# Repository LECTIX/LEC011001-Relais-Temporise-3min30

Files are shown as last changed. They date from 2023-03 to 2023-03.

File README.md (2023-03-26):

# LEC011001-Relais-Temporise-3min30
Fichiers sources pour le produit LEC011001

## Description du produit

Lorsque les 2 bornes BTN sont reliées via un bouton poussoir, un ILS ou équivalent, le relais reste activé pour une temporisation réglable entre 1s et 3min 30s.

- **ACTIVATION** Reliez les 2 bornes (avec un bouton poussoir, ILS, ou équivalent) pour enclencher le relais pour un temps réglable de 1s à 3min 30s.
- **RÉGLAGE** Réglez simplement la temporisation en utilisant un tournevis pour ajuster le potentiomètre.
- **ALIMENTATION** 8 – 16 V DC / AC (12V DC recommandé)
- **APPLICATIONS** Déclenchez facilement automatismes, animations et éclairages pendant un certain temps, ou après un certain délais.

## Utiliser les fichiers sources pour fabriquer le produit

Il n'est **pas nécessaire de savoir souder ou d'être bon en électronique** pour se procurer ce produit. Grâce aux fichiers sources publiés ici, vous pouvez être en mesure de faire fabriquer ce produit par un sous traitant.

### Faire fabriquer chez un sous traitant

Il est aujourd'hui possible de faire fabriquer à moindre cout des cartes électroniques. Nous recommendons [JLCPCB](https://jlcpcb.com/) si vous voulez aller au moins cher. Si vous préférez un acteur européen, [eurocircuits](https://www.eurocircuits.com/) est un des acteurs reconnus.

tuto (http://www.youtube.com/watch?v=RXGGvsUtz0c "TUTO : faire fabriquer un produit LECTIX")

1. Télécherger les sources de ce produit en cliquant sur le bouton `Code`, puis `Download ZIP`.
1. Décompresser le dossier.
1. Les fichiers pour la fabrication se trouvent dans le répertoire `hardware/prod`.
1. Se connecter sur [https://cart.jlcpcb.com/quote](https://cart.jlcpcb.com/quote)
1. Cliquer sur le bouton `Add gerber file` et sélectionner le fichier `gerbers.zip`.
1. Sélectionnez la quantité de cartes que vous souhaitez dans le champs `PCB Qty`.
1. Laisser toutes les autres options par défaut, puis cliquez sur le toggle switch en face de `PCB Assembly`, et enfin sur le bouton `confirm`.
1. Une preview de la carte électronique sans les composants doit apparaitre. Cliquez sur `NEXT`.
1. Cliquez sur le bouton `Add BOM File`, puis sélectionnez le fichier `bom.csv`
1. Cliquez sur le bouton `Add CPL File`, puis sélectionnez le fichier `pos.csv`
1. **Vérifier que tous les composants sont en stock** et bien sélectionnés, puis cliquez sur `NEXT`.
1. Une preview de la carte avec ses composants apparait. Continuer le chemin en cliquant sur `NEXT`.
1. Le prix final apparait. Sélectionnez la catégorie du produit, puis cliquez sur `SAVE TO CART`.
1. Une fois sauvegardé dans votre panier, vous pouvez valider votre commande et choisir le moyen d'acheminement. Afin de ne pas avoir à se préoccuper des frais de douane, nous vous conseillons de choisir une méthode d'expédition DDP.

Vous receverez vos cartes sous 1 à 3 semaines. 

**Nous ne sommes en aucun cas responsables des cartes qui arriveraient défectueuses ou non fonctionnelles.**

### Modifications des fichiers sources

Installez kicad 6 (ou version supérieure), et ouvrez le fichier LEC011001.kicad_pro

### Regénérer les fichiers gerber, BOM, et position (Optionnel)

Peut se faire simplement en utilisant kikit :

```
cd hardware
docker run --rm -w /kikit -v $PWD:/kikit yaqwsx/kikit kikit fab jlcpcb --assembly --no-drc --schematic LEC011001.kicad_sch --field LCSC --corrections JLCPCB_CORRECTION --nametemplate LEC011001_{} LEC011001.kicad_pcb prod/

```
## Notices

[Manuel FR](docs/manual_fr.pdf)

## License
Tous nos fichiers sont plubliés sous la license CERN Open Hardware Licence Version 2 - Strongly Reciprocal

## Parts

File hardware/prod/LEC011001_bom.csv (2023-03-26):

Comment | Designator | Footprint | LCSC
100uF | C1,C3,C7 | 0_capacitors:CP_Elec_6.3x5.8 | C249982
100nF | C2,C4,C5,C6,C8 | Capacitor_SMD:C_0603_1608Metric | C14663
MB10S | D1 | Package_TO_SOT_SMD:TO-269AA | C2488
LED | D2 | LED_SMD:LED_0603_1608Metric | C72043
D | D3 | Diode_SMD:D_SMA | C95872
Button | J1 | 0_connectors:TerminalBlock_bornier-2_P5.08mm-blue | C395882
PWR | J2 | 0_connectors:TerminalBlock_bornier-2_P5.08mm-green | C395849
CONTACT_1 | J3 | 0_connectors:TerminalBlock_bornier-3_P5.08mm-blue | C395881
CONTACT_2 | J4 | 0_connectors:TerminalBlock_bornier-3_P5.08mm-blue | C395881
HK19F-5V | K1 | 0_relays:Relay_DPDT_HK19F | C54512
S8050 | Q1 | Package_TO_SOT_SMD:SOT-23 | C2146
10k | R1,R2,R4 | Resistor_SMD:R_0603_1608Metric | C25804
1k | R3 | Resistor_SMD:R_0603_1608Metric | C21190
2M | RV1 | 0_potentiometers:Potentiometer_3296W_Vertical | C118923
MC78M05_TO252 | U1 | Package_TO_SOT_SMD:TO-252-2 | C58069
NE555D | U2 | Package_SO:SOIC-8_3.9x4.9mm_P1.27mm | C7593

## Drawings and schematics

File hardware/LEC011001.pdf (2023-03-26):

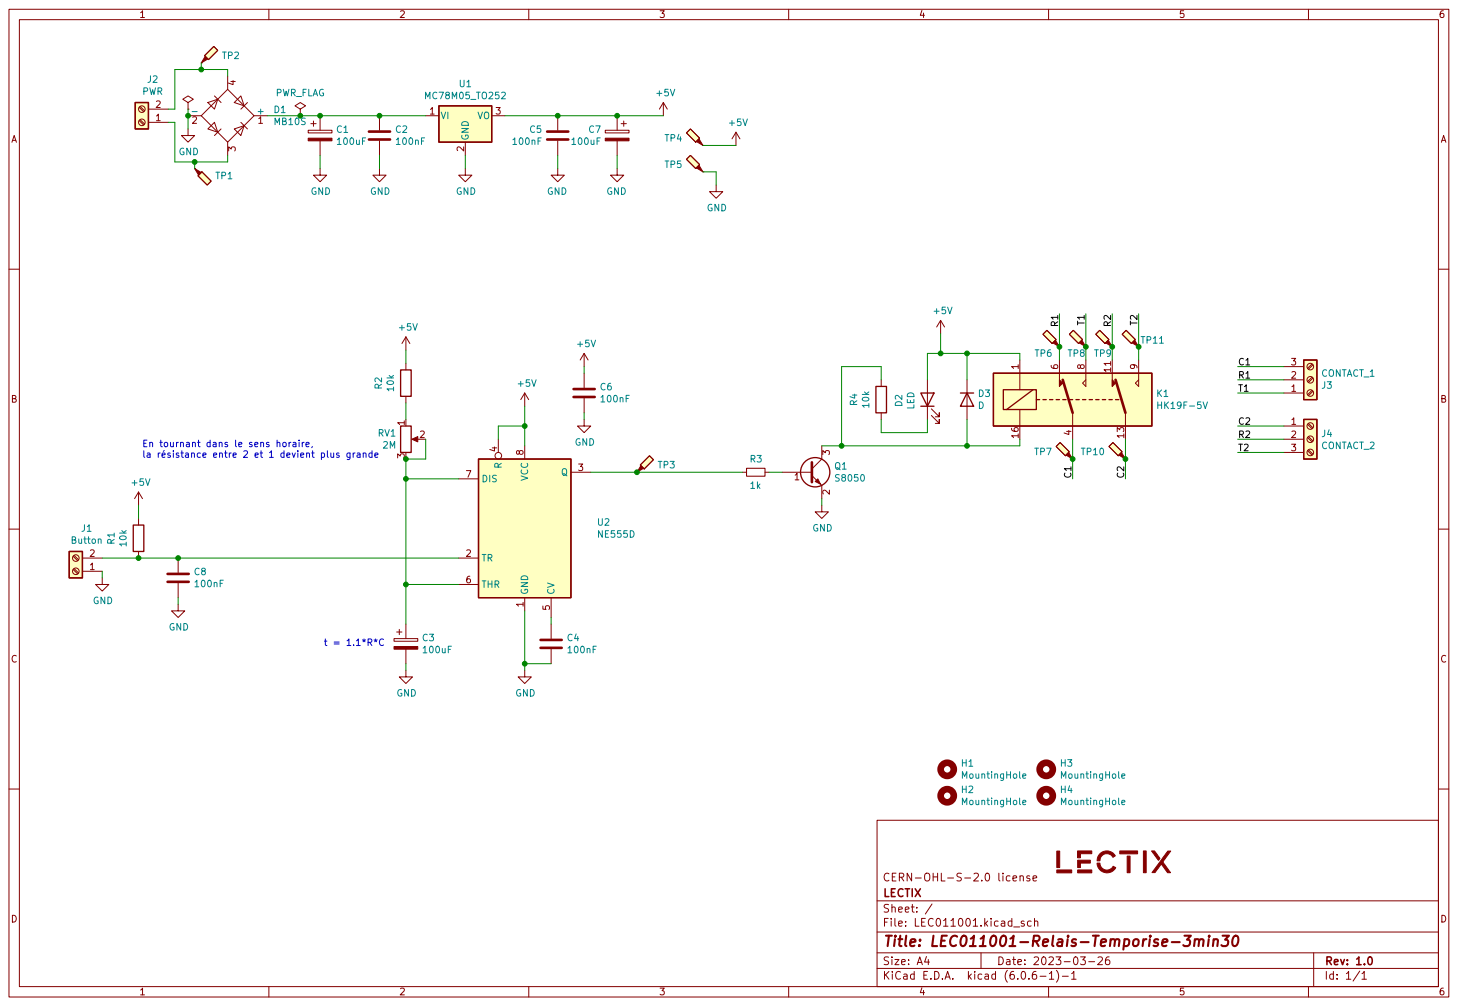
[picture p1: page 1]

File: LEC011001.kicad_sch Sheet: / LECTIX CERN-OHL-S-2.0 license

Id: 1/1 Title: LEC011001-Relais-Temporise-3min30

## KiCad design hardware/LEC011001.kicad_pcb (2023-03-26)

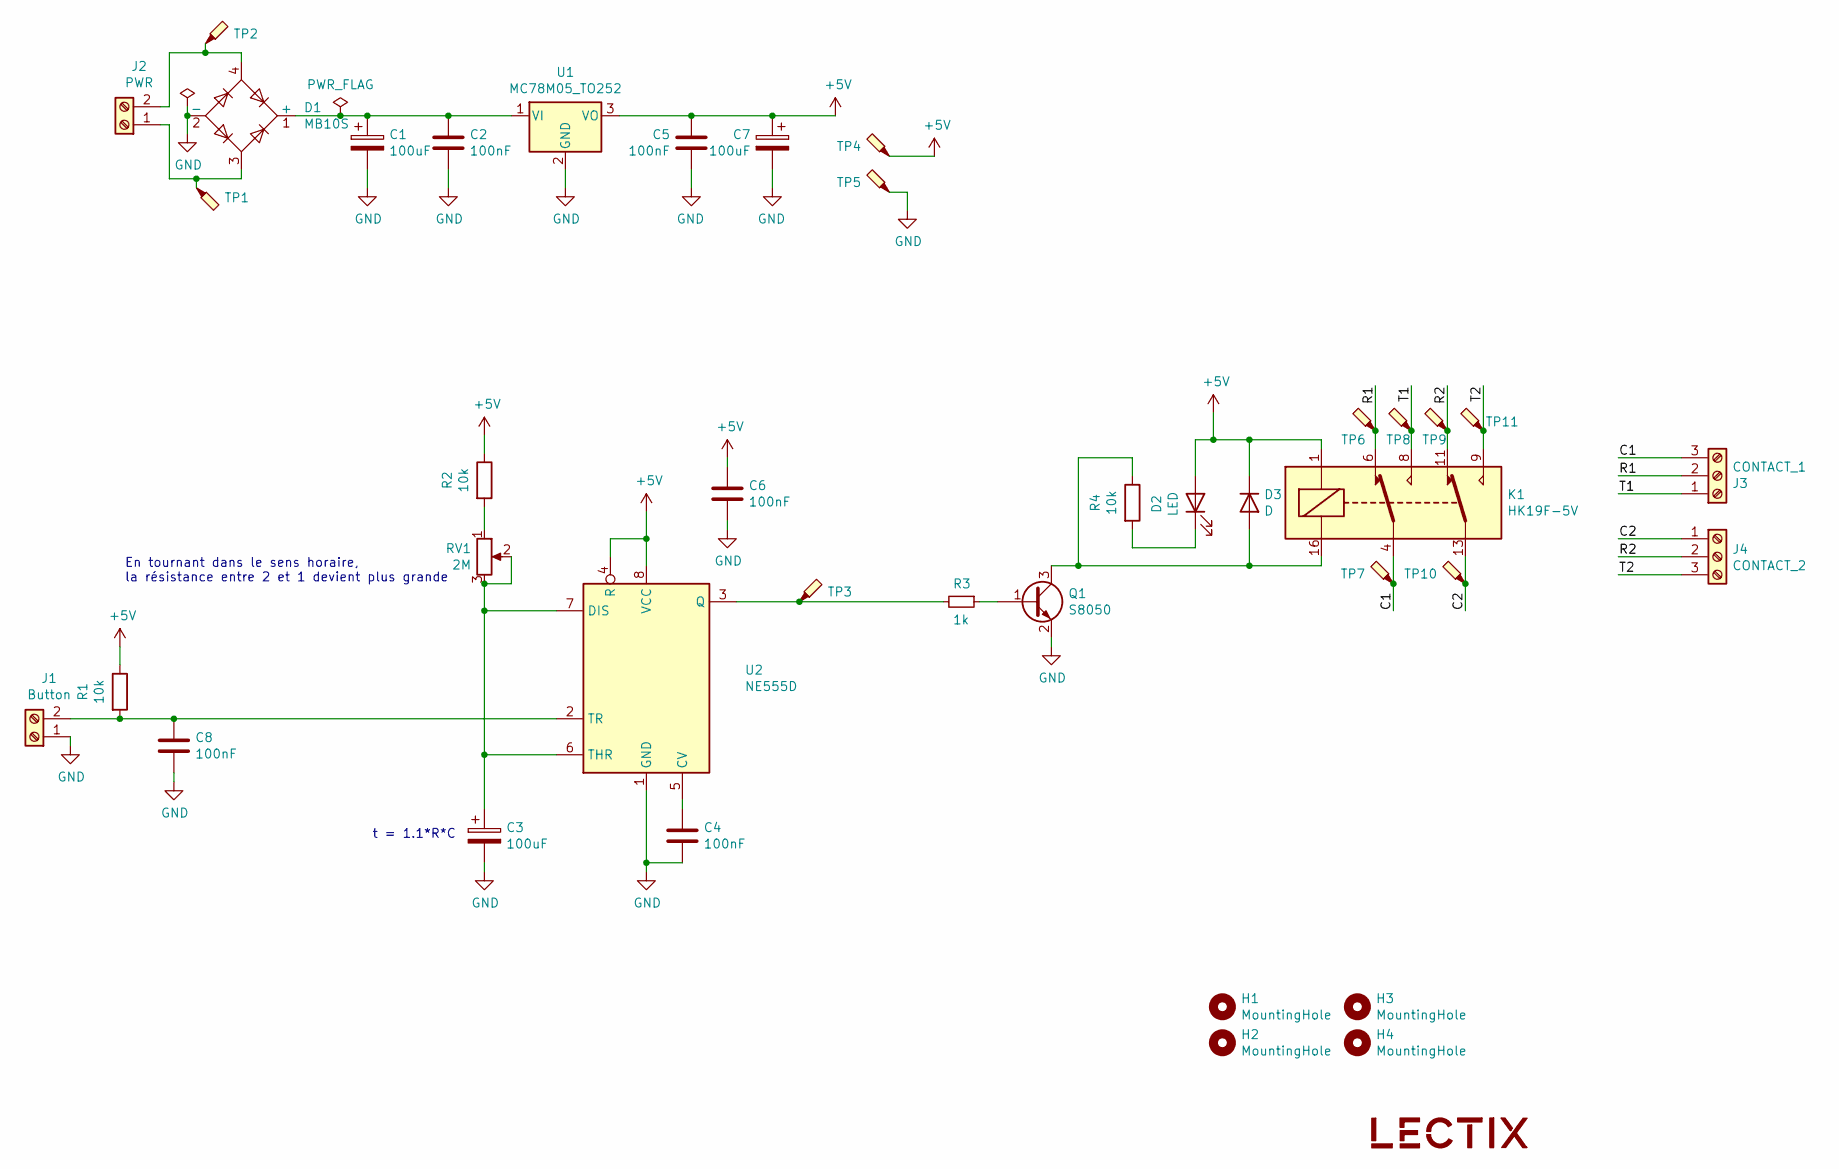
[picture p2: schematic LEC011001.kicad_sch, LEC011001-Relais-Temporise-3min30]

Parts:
C1, C3, C7: 100uF; CP_Elec_6.3x5.8; MPN VZT101M1VTR-0606; LCSC C249982
C2, C4, C5, C6, C8: 100nF; C_0603_1608Metric; MPN CC0603KRX7R9BB104; LCSC C14663
D1: MB10S; TO-269AA; MPN MB10S; LCSC C2488
D2: LED; LED_0603_1608Metric; MPN 19-217/GHC-YR1S2/3T; LCSC C72043
D3: D; D_SMA; MPN M7; LCSC C95872
H1, H2, H3, H4: MountingHole; MountingHole_3.2mm_M3; MPN DNP
J1: Button; TerminalBlock_bornier-2_P5.08mm-blue; MPN DB301V-5.0-2P-BU-S; LCSC C395882
J2: PWR; TerminalBlock_bornier-2_P5.08mm-green; LCSC C395849
J3: CONTACT_1; TerminalBlock_bornier-3_P5.08mm-blue; MPN DB301V-5.0-3P-BU-S; LCSC C395881
J4: CONTACT_2; TerminalBlock_bornier-3_P5.08mm-blue; MPN DB301V-5.0-3P-BU-S; LCSC C395881
K1: HK19F-5V; Relay_DPDT_HK19F; MPN HK19F-DC5V-SHG-Y; LCSC C54512
LOGO1: logo_lectix_25mm; Logo_10mm; MPN DNP
Q1: S8050; SOT-23; MPN S8050; LCSC C2146
R1, R2, R4: 10k; R_0603_1608Metric; MPN 0603WAF1002T5E; LCSC C25804
R3: 1k; R_0603_1608Metric; MPN 0603WAF1001T5E; LCSC C21190
RV1: 2M; Potentiometer_3296W_Vertical; MPN 3296W-1-205; LCSC C118923
TP1, TP2, TP3, TP4, TP5, TP6, TP7, TP8, TP9, TP10, TP11: TestPoint_Probe; TestPoint_Pad_D1.5mm; MPN DNP
U1: MC78M05_TO252; TO-252-2; LCSC C58069
U2: NE555D; SOIC-8_3.9x4.9mm_P1.27mm; MPN NE555D; LCSC C7593

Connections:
+5V: C5.1, C6.1, C7.1, D2.2 (A), D3.1 (K), K1.1, R1.1, R2.1, TP4.1, U1.3 (VO), U2.4 (R), U2.8 (VCC)
/C1: J3.3, K1.4, TP7.1
/C2: J4.1, K1.13, TP10.1
/R1: J3.2, K1.6, TP6.1
/R2: J4.2, K1.11, TP9.1
/T1: J3.1, K1.8, TP8.1
/T2: J4.3, K1.9, TP11.1
GND: C1.2, C2.2, C3.2, C4.2, C5.2, C6.2, C7.2, C8.2, D1.2 (-), J1.1, Q1.2 (E), TP5.1, U1.2 (GND), U2.1 (GND)
unnamed: C1.1, C2.1, D1.1 (+), U1.1 (VI)
unnamed: C3.1, RV1.2, RV1.3, U2.6 (THR), U2.7 (DIS)
unnamed: C4.1, U2.5 (CV)
unnamed: D1.3, J2.1, TP1.1
unnamed: D1.4, J2.2, TP2.1
unnamed: D2.1 (K), R4.2
unnamed: D3.2 (A), K1.16, Q1.3 (C), R4.1
unnamed: C8.1, J1.2, R1.2, U2.2 (TR)
unnamed: Q1.1 (B), R3.1
unnamed: R2.2, RV1.1
unnamed: R3.2, TP3.1, U2.3 (Q)

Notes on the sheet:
t = 1.1*R*C
En tournant dans le sens horaire, la résistance entre 2 et 1 devient plus grande

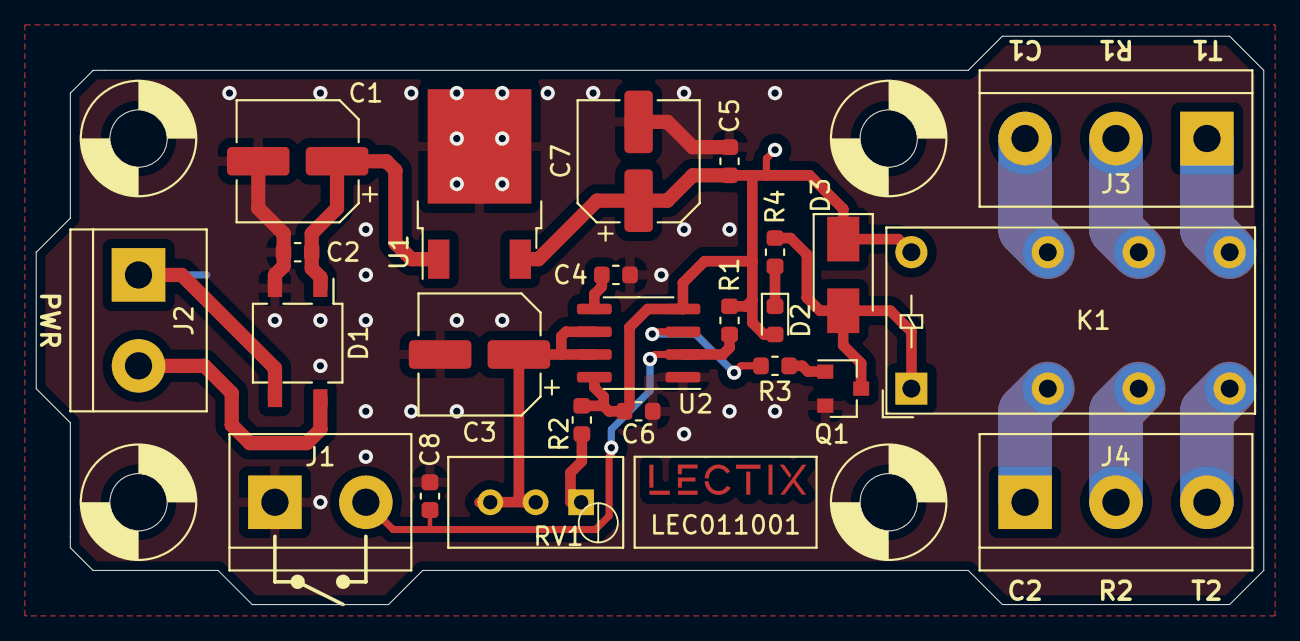
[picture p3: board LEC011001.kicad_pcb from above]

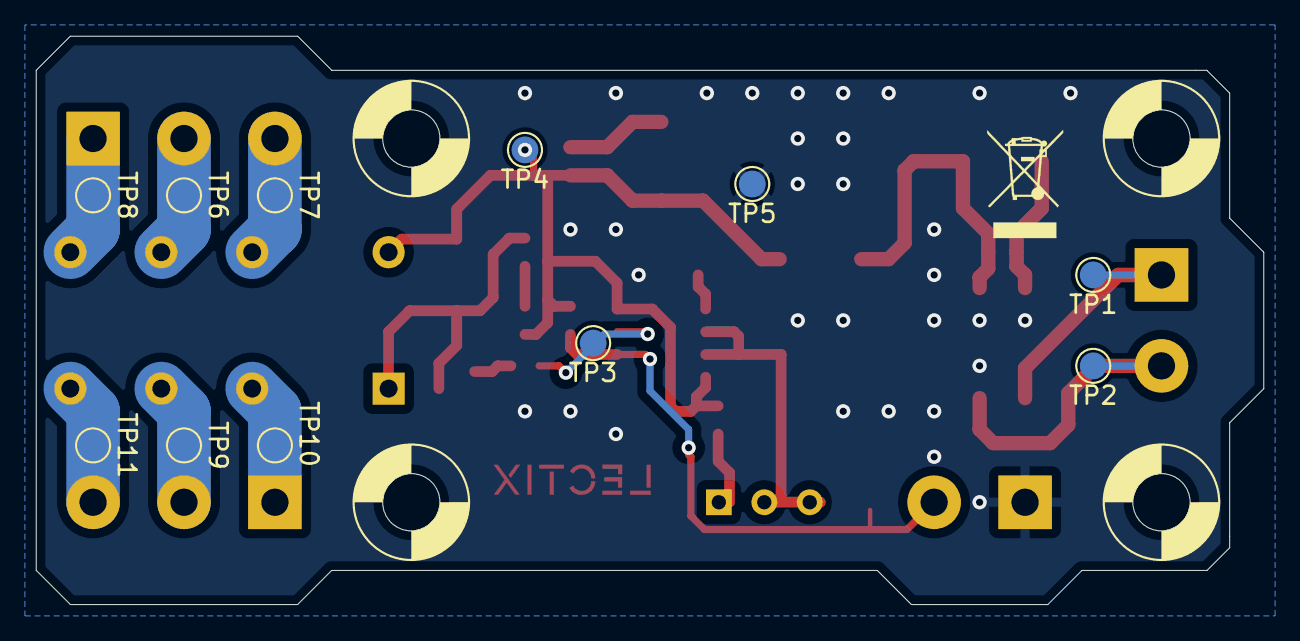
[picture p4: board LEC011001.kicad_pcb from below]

Board: 2 copper layers, 68.6 x 31.8 mm, 40 parts (11 on the bottom side), 19 nets.

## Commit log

2023-03-26 Add source files
    [LEC011001.kicad_pcb, LEC011001.kicad_sch]
2023-03-26 Add prod files
    [LEC011001-CmtUser.gbr, LEC011001-CuBottom.gbl, LEC011001-CuTop.gtl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]
2023-03-26 Add pdf schematic file
